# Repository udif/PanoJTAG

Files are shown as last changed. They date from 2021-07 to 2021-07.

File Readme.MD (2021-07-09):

This is a KiCAD design (5.99 based) for a voltage level translator that can fit inside the PanoLogic G2. It is intended to develop a cheap JTAG probe by handling the voltage conversion part.
A TX0104B-based design was considered, but abandoned since it has many problems:
* Cannot use in any designs with pullups or pulldowns below 50K
* Max JTAG pin capacitance must be 70pF (which is probably OK, but you need to check that)

Instead, the sn74avc4t774pw was chosen because it used acive drivers with individual direction pins.
The only limitation is that the maximum voltage it can drive is 3.6v which is OK for us.

Note that J3 is optional and only used for debugging the JTAG programmer itself.

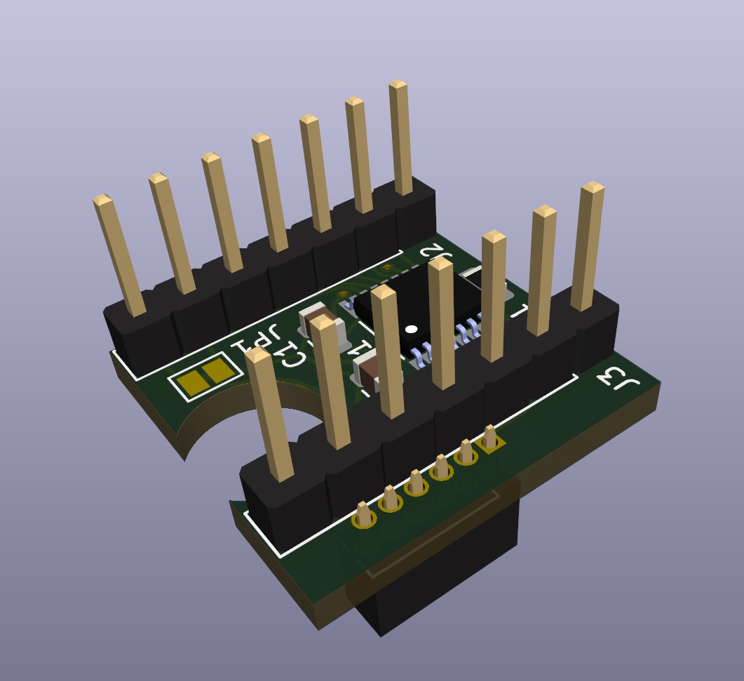
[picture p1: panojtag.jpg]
3D Render


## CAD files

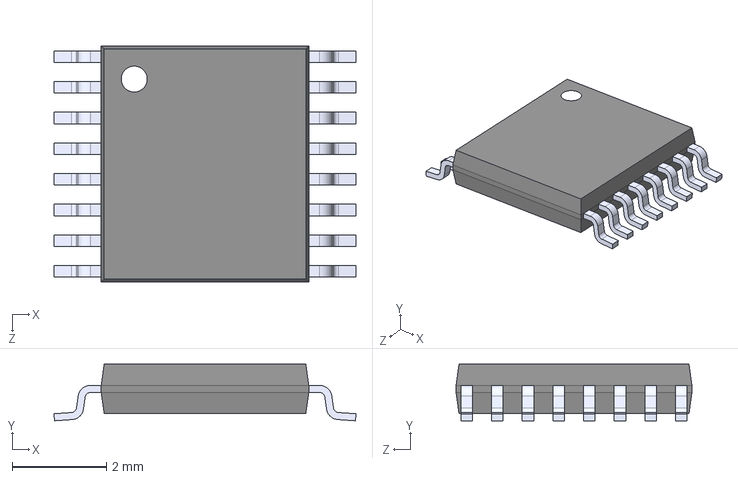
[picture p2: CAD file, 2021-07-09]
panojtag-sn74avc4t774pw/3dmodels/SN74AVC4T774PW.step
6.40 x 1.20 x 5.00 mm

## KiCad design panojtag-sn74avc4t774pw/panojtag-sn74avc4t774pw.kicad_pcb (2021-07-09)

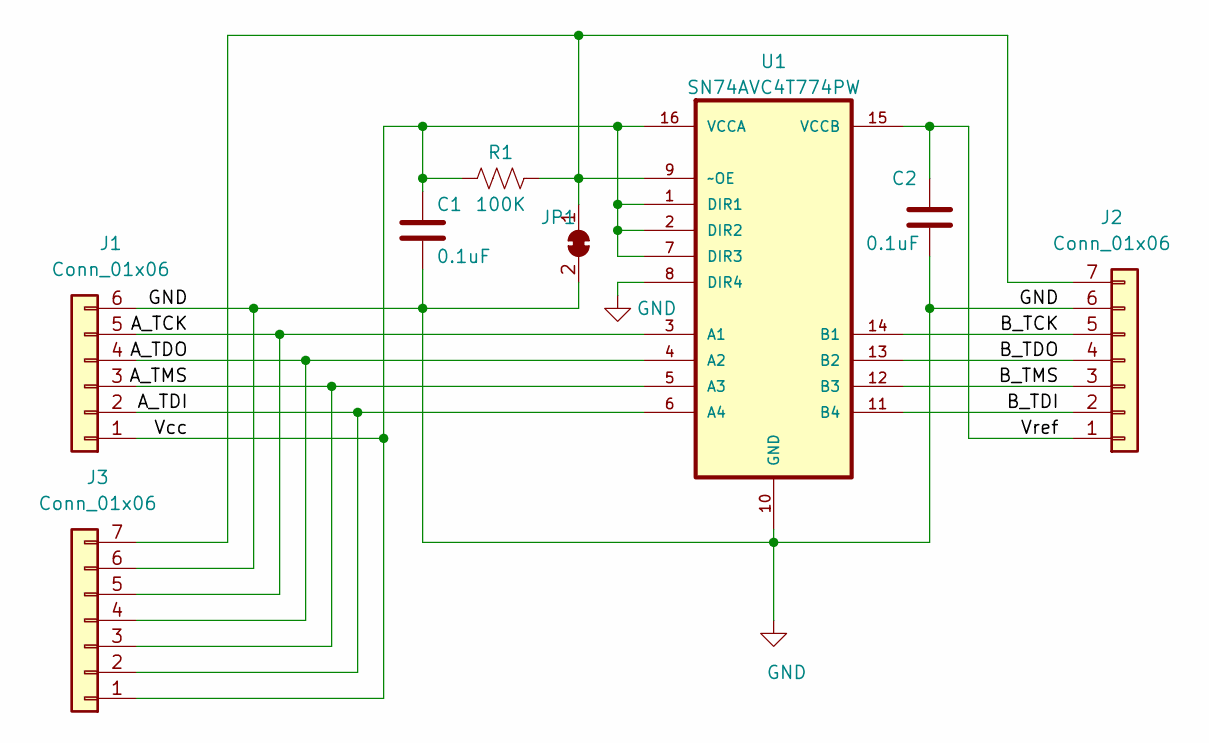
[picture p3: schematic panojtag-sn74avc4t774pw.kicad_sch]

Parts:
C1, C2: 0.1uF; C_0805_2012Metric
J1: Conn_01x06; PinSocket_1x06_P1.27mm_Vertical
J2, J3: Conn_01x06; PinHeader_1x07_P2.54mm_Vertical
JP1: SolderJumper_2_Bridged; SolderJumper-2_P1.3mm_Bridged_Pad1.0x1.5mm
R1: 100K; R_0805_2012Metric_Pad1.20x1.40mm_HandSolder
U1: SN74AVC4T774PW; SOP65P640X120-16N

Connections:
/A_TCK: J1.5, J3.5, U1.3 (A1)
/A_TDI: J1.2, J3.2, U1.6 (A4)
/A_TDO: J1.4, J3.4, U1.4 (A2)
/A_TMS: J1.3, J3.3, U1.5 (A3)
/B_TCK: J2.5, U1.14 (B1)
/B_TDI: J2.2, U1.11 (B4)
/B_TDO: J2.4, U1.13 (B2)
/B_TMS: J2.3, U1.12 (B3)
/Vcc: C1.1, J1.1, J3.1, R1.1, U1.1 (DIR1), U1.2 (DIR2), U1.7 (DIR3), U1.16 (VCCA)
/Vref: C2.1, J2.1, U1.15 (VCCB)
GND: C1.2, C2.2, J1.6, J2.6, J3.6, JP1.2 (B), U1.8 (DIR4), U1.10 (GND)
unnamed: J2.7, J3.7, JP1.1 (A), R1.2, U1.9 (~OE)

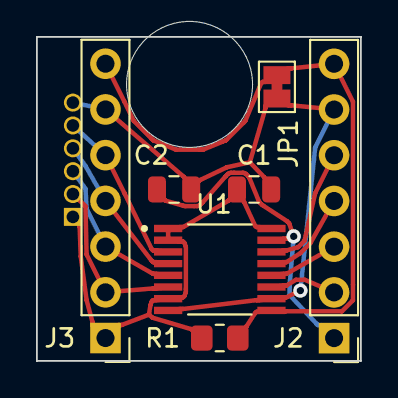
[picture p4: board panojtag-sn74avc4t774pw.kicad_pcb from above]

Board: 2 copper layers, 18.0 x 18.0 mm, 8 parts (1 on the bottom side), 12 nets.

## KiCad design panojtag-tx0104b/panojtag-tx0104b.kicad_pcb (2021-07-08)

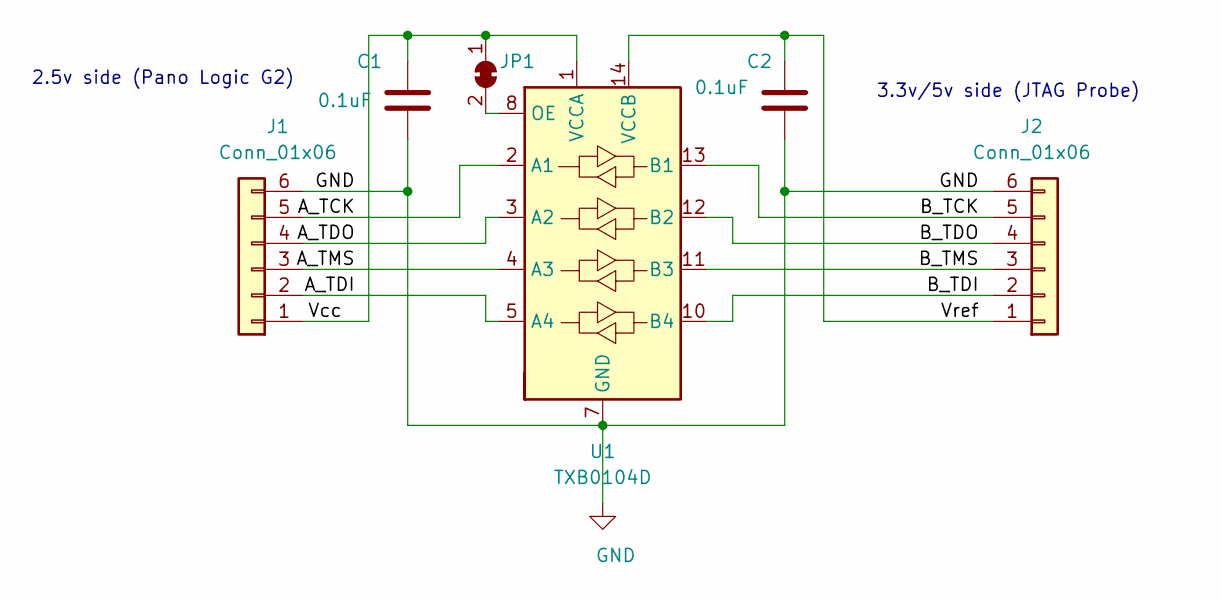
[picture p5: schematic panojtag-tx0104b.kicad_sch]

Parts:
C1, C2: 0.1uF; C_0805_2012Metric
J1: Conn_01x06; PinHeader_1x06_P1.27mm_Vertical
J2: Conn_01x06; PinHeader_1x06_P2.54mm_Vertical
JP1: SolderJumper_2_Bridged; SolderJumper-2_P1.3mm_Bridged_Pad1.0x1.5mm
U1: TXB0104D; SOIC-14_3.9x8.7mm_P1.27mm

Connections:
/A_TCK: J1.5, U1.2 (A1)
/A_TDI: J1.2, U1.5 (A4)
/A_TDO: J1.4, U1.3 (A2)
/A_TMS: J1.3, U1.4 (A3)
/B_TCK: J2.5, U1.13 (B1)
/B_TDI: J2.2, U1.10 (B4)
/B_TDO: J2.4, U1.12 (B2)
/B_TMS: J2.3, U1.11 (B3)
/Vcc: C1.1, J1.1, JP1.1 (A), U1.1 (VCCA)
/Vref: C2.1, J2.1, U1.14 (VCCB)
GND: C1.2, C2.2, J1.6, J2.6, U1.7 (GND)
unnamed: JP1.2 (B), U1.8 (OE)

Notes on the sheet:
2.5v side (Pano Logic G2)
3.3v/5v side (JTAG Probe)

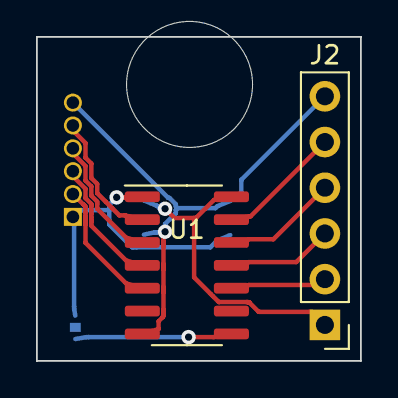
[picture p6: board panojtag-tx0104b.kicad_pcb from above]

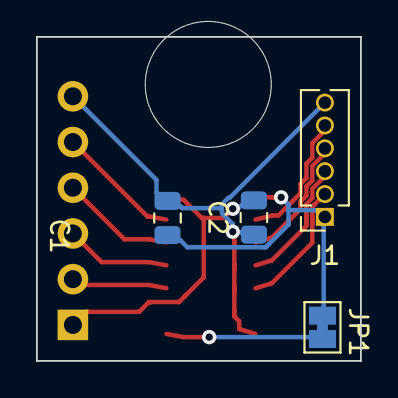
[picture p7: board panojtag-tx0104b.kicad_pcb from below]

Board: 2 copper layers, 18.0 x 18.0 mm, 6 parts (4 on the bottom side), 12 nets.

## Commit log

2021-07-08 Initial version based on TX0104B
    [panojtag.kicad_pcb, panojtag.kicad_sch]
2021-07-08 renamed files before changing design
    [panojtag-tx0104b.kicad_pcb, panojtag-tx0104b.kicad_sch]
2021-07-08 Moved TX0104B to its own subdir.
    [panojtag-tx0104b.kicad_pcb, panojtag-tx0104b.kicad_sch]
2021-07-08 Cleaned up and routed TX0104B version, but e're not going to use it. Routed using TopoR with 45deg tracks.
    [panojtag-tx0104b.kicad_pcb, panojtag-tx0104b.kicad_sch]
2021-07-09 Initial commit for sn74avc4t774pw based design Added another 100mil connector for JTAG debugging Added 7th pin for optional driver /OE control.
    [SN74AVC4T774PW.step, panojtag-sn74avc4t774pw.kicad_pcb, panojtag-sn74avc4t774pw.kicad_sch]
